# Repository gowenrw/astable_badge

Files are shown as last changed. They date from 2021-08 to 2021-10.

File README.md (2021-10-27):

# astable_badge
BSidesDFW 2021 Badge - Astable Multivibrator - Learn To Solder/Electronics/DIY

This is where all the files for the astable_badge will be stored.  
This includes code and art and cad and fab files.  All the things.

## File Structure

This is the file structure of this repository

* [/](/README.md) - YOU ARE HERE
* [/art/](./art/) - Artwork and other graphics created by this project
* [/code/](./code/) - All project related Code / Firmware
* [/docs/](./docs/) - Documentation created by this project including web pages
* [/eda/](./eda/) - Electronic Design Automation files (i.e. KiCad)
* [/reference_parts/](./reference_parts/) - Documentation pulled from other sources related to components (this is a submodule, see below)
* [./README.md](/README.md) - This File
* [./LICENSE](/LICENSE) - Currently set to MIT

Note: the reference_parts directory a link to a submodule repository.
To add it use the following cmd after downloading this template:
```
git submodule add https://github.com/gowenrw/reference_parts reference_parts
```
This will make a link to the current commit of that repo.
To update it to a newer commit after its been added use this cmd:
```
git submodule update --recursive
```

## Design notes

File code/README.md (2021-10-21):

# Code

This is where all the all project related Code / Firmware is located

## File Structure

This is the file structure of this repository

* [/](/README.md) - Home
* [/code/](/code/) - YOU ARE HERE
  * [/code/altbier_pcb/](/code/altbier_pcb/) - Code folder for the PCB(s)
  * [/code/include/](/code/include/) - Common code includes (e.g. chipset drivers, etc.) used by the other code folders

NOTE: This project has no code since it does not use an IC.

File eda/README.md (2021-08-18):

# Electronic Design Automation

This is where all the Electronic Design Automation files for the PCB(s) will be stored.
The EDA used is KiCad 5.x unless otherwise specified.

The KiCad projects have been configured to use local libraries for long term sustainability per the best practices listed [HERE](https://hackaday.com/2017/05/18/kicad-best-practises-library-management/) and elsewhere.

## File Structure

This is the file structure of this repository

* [/](/README.md) - Home
* [/eda](/eda/) - YOU ARE HERE
  * /eda/astable_badge/ - KiCad project folder for the badge PCB
    * ./3d_models/ - This directory contains footprint 3d model files
    * ./gerber/ - This directory contains gerber formatted files for manufacturing
    * ./lib_fp/ - This directory contains footprint module directories
    * ./lib_sh/ - This directory contains schematic library files
    * ./snapshots/ - This directory contains prints of schematic / cad files and images of preview / final product
  * /eda/astable_dev/ - KiCad project folder for the development PCB
    * ./3d_models/ - This directory contains footprint 3d model files
    * ./gerber/ - This directory contains gerber formatted files for manufacturing
    * ./lib_fp/ - This directory contains footprint module directories
    * ./lib_sh/ - This directory contains schematic library files
    * ./snapshots/ - This directory contains prints of schematic / cad files and images of preview / final product

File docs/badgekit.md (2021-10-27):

---
layout: default
---

# BSidesDFW 2021 Astable Badge Kit

The Astable Badge Kit contains the following items:

*  1 - PCB
*  1 - Lanyard
*  1 - Sticker
*  1 - CR2032 Battery
*  1 - Small Static Bag with the following components:
    *  5 - 3mm LEDs (1 each of Red, Green, Blue, Yellow, and White)
    *  2 - 10 ohm Resistors
    *  2 - 510 ohm Resistors
    *  2 - 1K ohm Resistors
    *  2 - 0-30K ohm Variable Resistors (a.k.a. Rheostats)
    *  2 - 100uF Polarized Capacitors
    *  2 - NPN BJT 2222A Transistors
    *  1 - CR2032 Battery Holder
    *  1 - 5x1 header pin segment

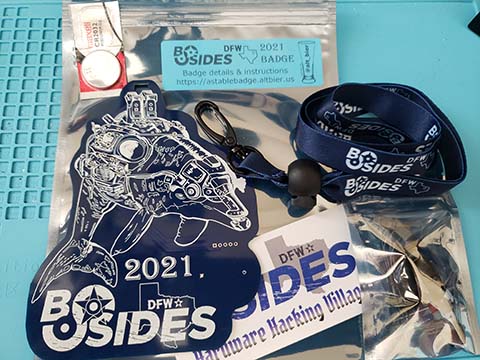
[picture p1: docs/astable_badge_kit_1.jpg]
Kit1

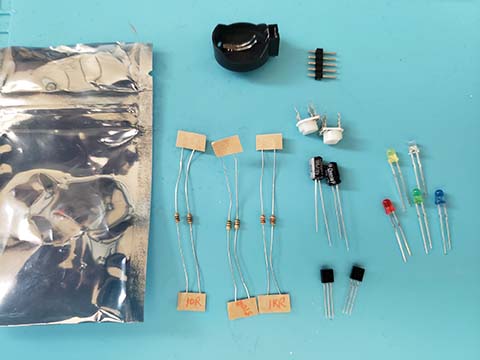
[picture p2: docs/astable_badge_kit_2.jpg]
Kit2


# Tools

In addition to the badge PCB and the small component bag that is provided, you will need the following tools:

* Soldering Iron and Solder

Any electronics soldering iron in the 40 Watt to 70 Watt range should work.  
Note that not all soldering irons are for electronics, those used for plumbing and other applications use much higher temperatures that could damage electronics.

There are different types of solder used for electronics and most of them will work fine.
The type I recommend for beginner's is 63-37 (or 60-40) Rosin Core 0.8mm solder.  
The 63-37 refers to the element percentages: 63 percent Tin and 37 percent Lead.
The Rosin Core indicates that the center of the solder wire is hollowed out and filled with Rosin which is a Flux material (so you do not need to apply Flux separately).
The diameter of 0.8mm seems to work best for most applications IMHO.

You can find kits on [Amazon](https://www.amazon.com/s?k=soldering+iron+kit) and elsewhere for less than $20 that include a Soldering Iron, Solder, a Stand, and other useful items.

* Diagonal Cutter

A good diagonal cutting tool is needed to trim the component leads once soldered.
Sometimes this is provided in a soldering iron kit.
But, usually those inexpensive kits do not provide a good cutter.

You can find a good Diagonal Cutter at [Amazon](https://www.amazon.com/s?k=diagonal+cutter) and elsewhere for less than $10.

* Small Screwdriver

A small Phillips head Screwdriver is needed for adjusting the Rheostats to change the speed at which the LEDs blink.

* Multimeter and Logic Analyzer (Optional)

Testing tools such as a multimeter and logic analyzer can be useful in troubleshooting issues with your build as well as learning the electronics that make up the badge.

You can find an inexpensive Multimeter on [Amazon](https://www.amazon.com/s?k=multimeter) and elsewhere for less than $10.

You can find an inexpensive USB Logic Analyzer on [Amazon](https://www.amazon.com/s?k=usb+logic+analyzer+-+24mhz+8-channel) and elsewhere for less than $15.

# Instructions

This is a learn to solder / electronics badge.
The schematic of the circuit you will be building is printed on the back of the badge.
In addition, the back of the badge details out the placement of the components to be soldered.

All of the components that you will be soldering have through hole or THT packaging.  This means that they have metal leads that will be placed into the appropriate holes in the PCB and soldered in place.

These components can be added and soldered to the PCB in any order you wish.  These instructions will outline how I build the badge, but feel free to build as you like.

## Resistors

There are a total of six resistors, two each of the values 10 Ohm, 510 Ohm, and 1K Ohm.

The resistors come attached to paper which has the value labeled on it.  If you need to determine the value of a resistor once removed from that paper you can view the colored stripes on the body of the resistor and look it up on a resistor value chart such as this one from [wikipedia](https://en.wikipedia.org/wiki/Electronic_color_code#Resistors).

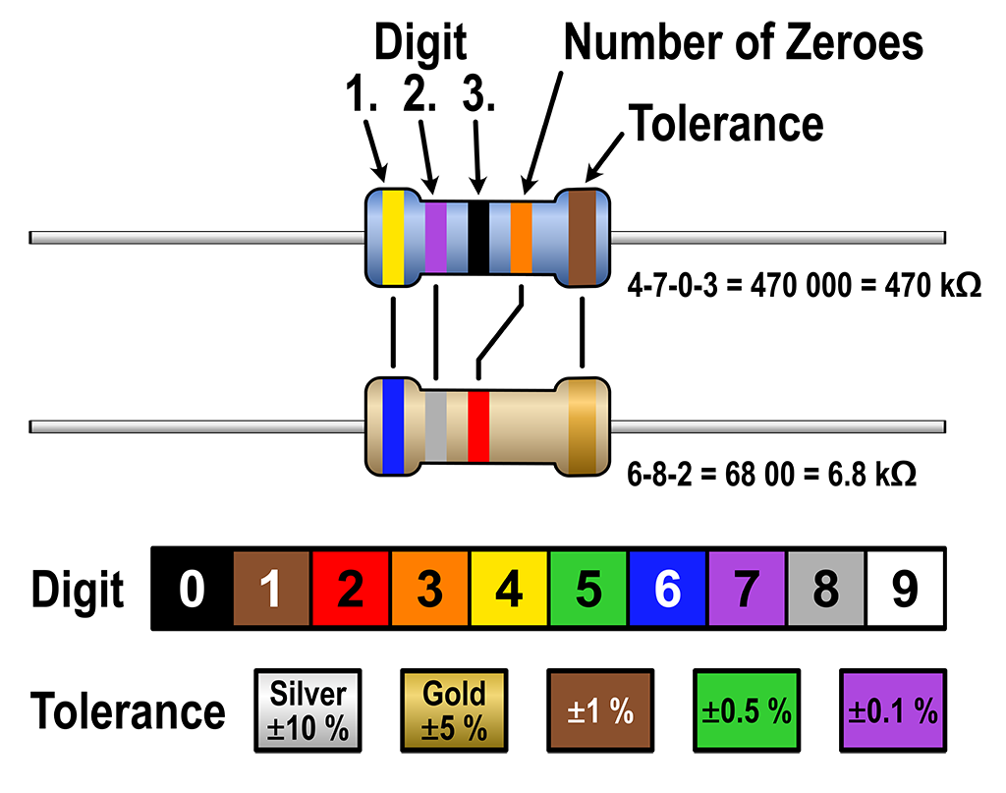
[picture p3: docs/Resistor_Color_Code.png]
Resistor_Color_Codes


Identify the area on the badge where the components will need to be installed by looking at the component labels on the back of the PCB.

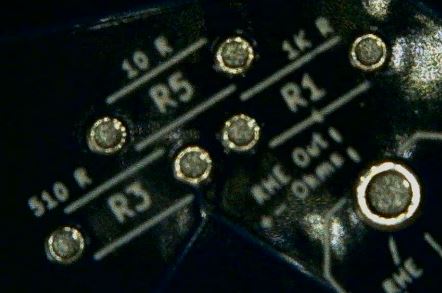
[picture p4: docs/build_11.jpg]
Build_11


Remove the resistors from the paper and bend their leads 90 degrees.

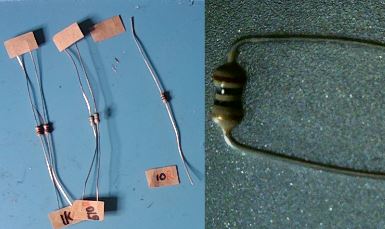
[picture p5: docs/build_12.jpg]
Build_12


Insert the resistors into the proper holes as labeled on the back of the PCB.

The resistor body should be on the front of the PCB with the leads coming through the holes to the back of the PCB.

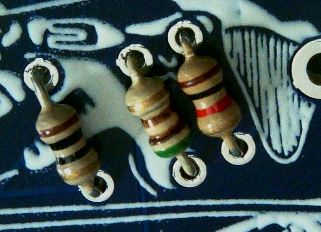
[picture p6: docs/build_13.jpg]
Build_13

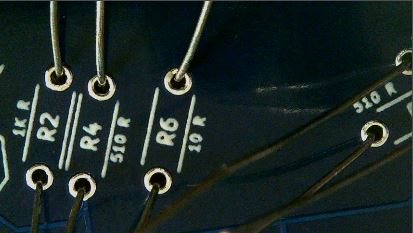
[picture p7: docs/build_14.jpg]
Build_14


Solder those leads in place.

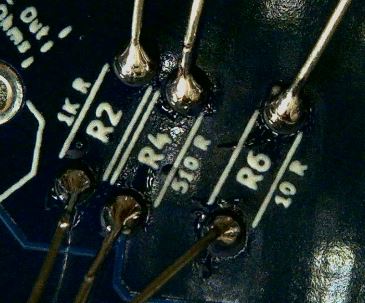
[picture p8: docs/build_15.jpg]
Build_15


Trim the leads with a diagonal cutter taking care not to trim too close to the solder joint.

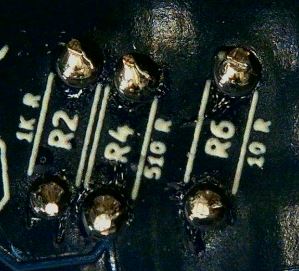
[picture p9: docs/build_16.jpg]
Build_16


## Transistors

There are two NPN BJT Transistors of the model 2222A.  

Identify the area on the badge where the components will need to be installed by looking at the component labels on the back of the PCB.

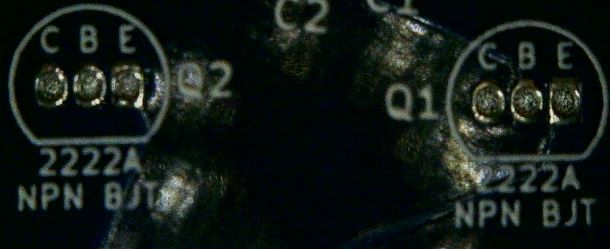
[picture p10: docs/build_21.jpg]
Build_21


These Transistors have a flat side and a rounded side to allow for proper alignment when placing on the PCB.

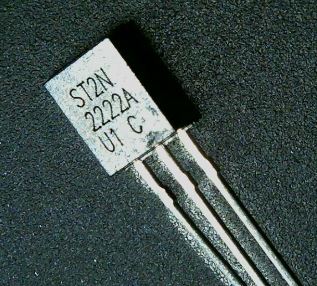
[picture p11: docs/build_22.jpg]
Build_22


Insert the Transistors into the proper holes as labeled on the back of the PCB.

The Transistor body should be on the front of the PCB with the leads coming through the holes to the back of the PCB.

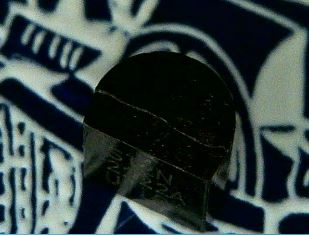
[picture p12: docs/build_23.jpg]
Build_23

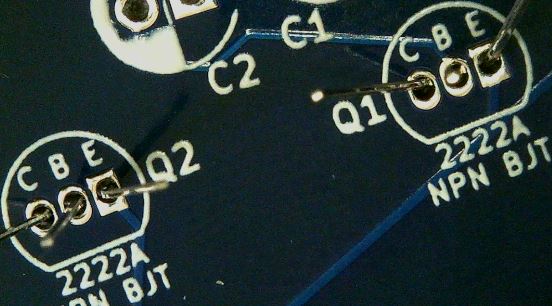
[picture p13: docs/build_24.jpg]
Build_24


Solder those leads in place.
The holes for these components are close together.
Be careful not to bridge (solder together) any of the Transistor connections.

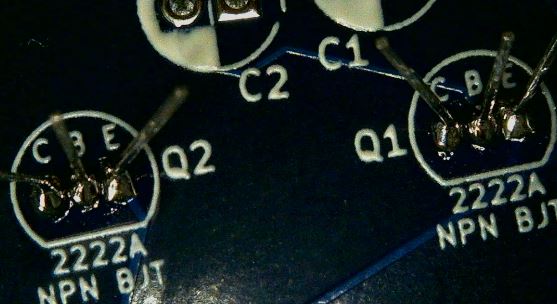
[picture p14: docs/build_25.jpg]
Build_25


Trim the leads with a diagonal cutter taking care not to trim too close to the solder joint.

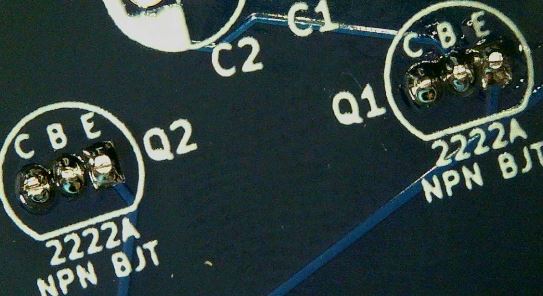
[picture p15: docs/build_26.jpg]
Build_26


## Rheostats (Variable Resistors)

There are two Variable Resistors also known as Rheostats which each have 3 pins and a resistance range of 0 to 30K Ohms.

Identify the area on the badge where the components will need to be installed by looking at the component labels on the back of the PCB.

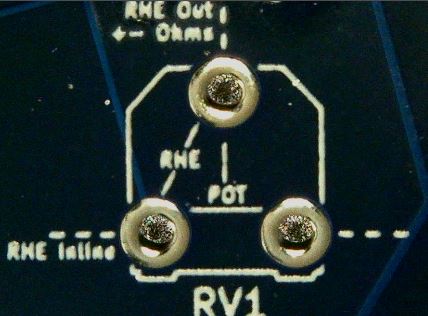
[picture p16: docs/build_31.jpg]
Build_31


These Rheostats have a unique shape with cutouts on one side to allow for proper alignment when placing on the PCB.

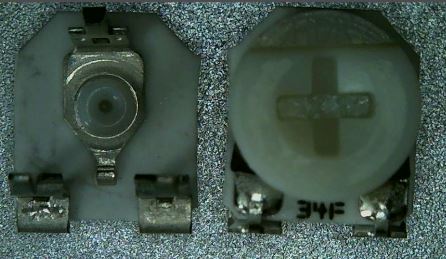
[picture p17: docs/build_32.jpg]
Build_32


Insert the Rheostats into the proper holes as labeled on the back of the PCB.

The Rheostats body should be on the front of the PCB with the leads coming through the holes to the back of the PCB.
Note that the leads are made in such a way as to act as standoffs keeping the body of the Rheostat raised above the PCB.

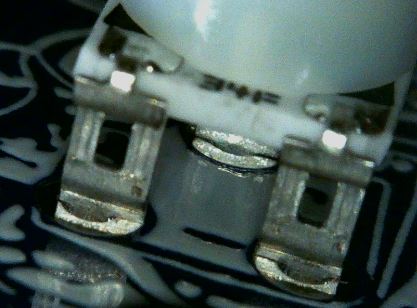
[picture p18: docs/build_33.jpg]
Build_33

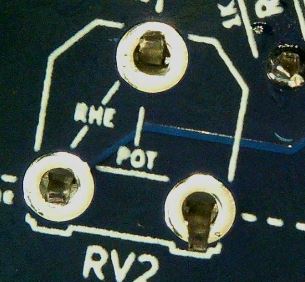
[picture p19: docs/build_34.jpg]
Build_34


Solder those leads in place.

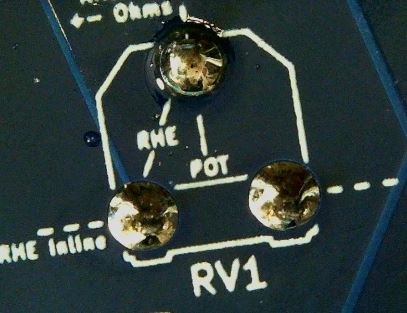
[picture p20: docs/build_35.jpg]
Build_35


These leads should be close enough to the PCB that they do not need to be trimmed with the cutter.

## Capacitors

There are two Polarized Capacitors with the value of 100uF 10V.  Polarized Capacitors are directional components that must be placed with positive and negative terminals in the proper direction.

Identify the area on the badge where the components will need to be installed by looking at the component labels on the back of the PCB.

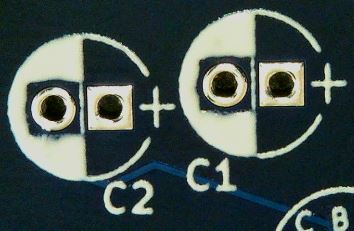
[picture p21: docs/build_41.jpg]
Build_41


These Capacitors have a white stripe indicating the negative terminal which also has a shorter lead wire.  This should allow for proper alignment when placing on the PCB.

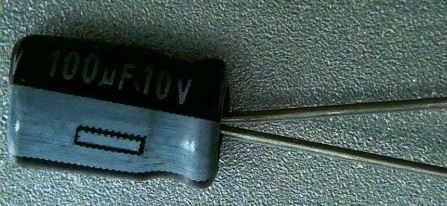
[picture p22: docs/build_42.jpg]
Build_42


Insert the Capacitors into the proper holes as labeled on the back of the PCB.

The Capacitor body should be on the front of the PCB with the leads coming through the holes to the back of the PCB.

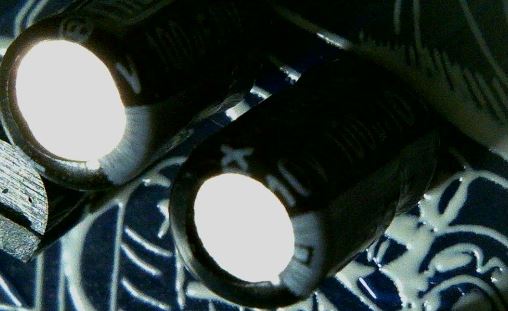
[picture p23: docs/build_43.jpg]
Build_43

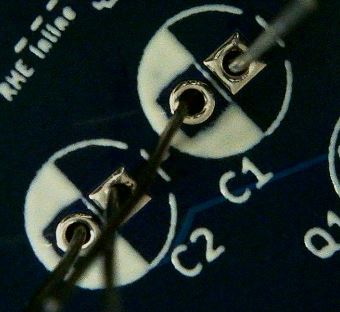
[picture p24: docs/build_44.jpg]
Build_44


Solder those leads in place.

Build_45

Trim the leads with a diagonal cutter taking care not to trim too close to the solder joint.

Build_46

## LEDs

There are two LEDs of the 3mm size that you will use on the badge.  These LEDs are directional components that must be placed with positive and negative terminals in the proper direction.

You were provided five LEDs in different colors to allow you to choose the two colors you would like to use.

Identify the area on the badge where the components will need to be installed by looking at the component labels on the back of the PCB.

Build_51

These LEDs have a small flat notch on the otherwise round base indicating the negative terminal which also has a shorter lead wire.  The PCB component label has a small triangle that points to the where the negative terminal should be placed. This should allow for proper alignment when placing on the PCB.

Build_52

Insert the LEDs into the proper holes as labeled on the back of the PCB.

The LED body should be on the front of the PCB with the leads coming through the holes to the back of the PCB.

Build_53
Build_54

Solder those leads in place.

Build_55

Trim the leads with a diagonal cutter taking care not to trim too close to the solder joint.

Build_56

## Battery Holder

There is one battery holder for a CR2032 sized battery.  It is directional in that it must be placed with positive and negative terminals in the proper direction.

Identify the area on the badge where the components will need to be installed by looking at the component labels on the back of the PCB.

Build_61

This battery holder has a distinctive shape that should allow for proper alignment when placing on the PCB.

Build_62

Insert the battery holder into the proper holes as labeled on the back of the PCB.

The battery holder body should be on the front of the PCB with the leads coming through the holes to the back of the PCB.

Build_63
Build_64

Solder those leads in place.

Build_65

These leads should be close enough to the PCB that they do not need to be trimmed with the cutter.

## Test Header Pins

The test header pins are an optional component you can add to aid with testing later.  These are standard 1.25mm pitch header pins in a single row of five pins.

Place these header pins into the proper holes as labeled on the back of the PCB.

Build_72

Solder those leads in place.

Build_75

These leads should be close enough to the PCB that they do not need to be trimmed with the cutter.

## Operational Test

To test the badge once you are finished building it simply insert a battery.

The CR2032 battery should be inserted into the battery holder with the Plus (+) sign showing up.

If all worked well you should see the two LEDs start to blink on and off.

You can adjust the speed that the LEDs blink by adjusting the Rheostats with a Screwdriver.

Build_80

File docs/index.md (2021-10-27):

---
layout: default
---

Hero Image

# Astable Badge

Welcome to the Astable Badge website.

This is where you will find information about the BSidesDFW 2021 Badge and its repository.

-- [@alt_bier](https://twitter.com/alt_bier)  - [My Contact Info](https://gowen.net/about)

Animated

---

# Badge Kit Instructions

If you are looking for what comes in the badge kit or instructions on how to build the badge, those details are here: [Badge Kit](badgekit.md)

# Concept

The concept for this badge started [@CyberLowdown](https://twitter.com/CyberLowdown) asking me if I would be willing to do the badge for the BSidesDFW 2021 conference and with [@0isac0](https://twitter.com/0isac0) asking me if we can do a [Johnny Mnemonic](https://www.imdb.com/title/tt0113481/) theme since that movie takes place in 2021.
After much research I settled on a Cyber-Dolphin for the principal focus of the badge.

Given how the global chip shortages affected my recent Defcon badge I needed a circuit design that would flash some LEDs without the use of an IC chip.  This is what drove the circuit design.

Another design factor was that I wanted to make it a learning badge (learn soldering and electronics).  I've had great feedback on my other learning badges and I thought this would be a great draw to the BSidesDFW Hardware Hacking Village (which I would be running) to help people build their badges.

## Art

The badge art using a Johnny Mnemonic theme had me stumped on what to do since I did not just want to put Keanu Reeves face on a PCB (plus that's been done before).

So I did some research online and still had nothing.  I then reached out to some other badge makers and the idea of the Cyborg or Cyber Dolphin was mentioned.  It had been a long time since I watched that movie and didn't remember a Dolphin so I re-watched it and sure enough it was there.  

I loved the aesthetic and the Cyber-Dolphin badge art was born.

Badge_Front_sm
CyberDolphin_sm

All of the Art files including the Adobe Illustrator files and various exported formats are available in the [art directory](https://github.com/gowenrw/astable_badge/tree/main/art) of this repository.

# Details

I wanted to make this a learn to solder and learn electronics badge.
All of the components are Through Hole type to meet the learn to solder goal.
The circuit needed to be complex enough to blink some LEDs without using an IC chip but simple enough for people to easily see what it is doing to learn from it.
The Astable Multivibrator circuit was perfect to meet the learn electronics goal.

Badge_Assembled

## Astable Multivibrator

The Astable Multivibrator is a type of transistor switching circuit that has NO stable output states as it changes from one state to the other all the time.

The astable circuit consists of two switching transistors getting feedback from two time delay capacitor-resistor couplings.
This allows oscillation between the two states with no external triggering to produce the change in state.

On this badge I opted to introduce variable resistors (Rheostats) into the time delay capacitor-resistor couplings to allow for the speed of the state changes to be adjusted.
I added LEDs to the outputs of this circuit providing visual representation of the circuit state changes (and blinky lights).
I also added test points to the PCB so that the alternating square waves produced by this circuit could be observed with a cheap logic analyzer.

Astable Multivibrator Circuit Schematic
Astable_Multivibrator

## EDA

The electronic design automation program used for this badge is KiCad.

I took great care to include and use local library files for all the schematic objects, footprints, and 3d models used in this badge.  
This way you don't have to worry about not having a file that KiCad depreciates at some point in the future.

All of the EDA files including the Gerber output files I used to have the badge manufactured are available in the [badge eda directory](https://github.com/gowenrw/astable_badge/tree/main/eda/astable_badge) of this repository.

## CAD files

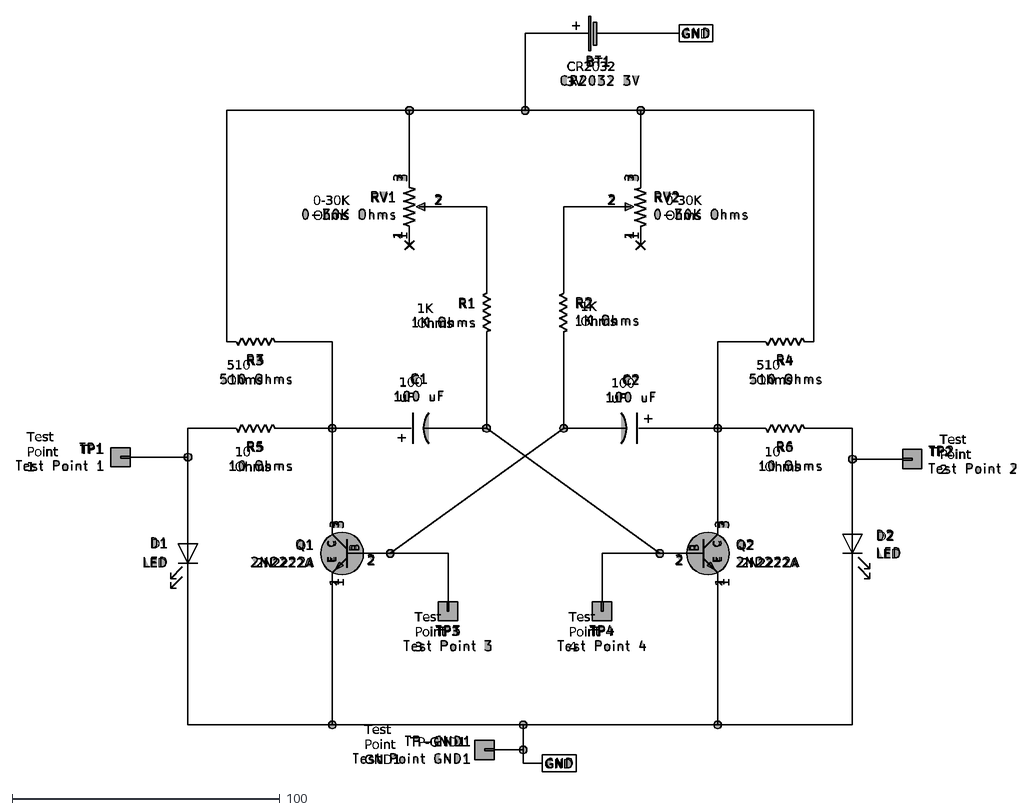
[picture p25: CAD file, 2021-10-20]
art/astable_badge_schem-back_silk.dxf
C1
100 uF
D2
LED
R4
510 Ohms
D1
TP1
Test Point 1
R3
TP-GND1
Test Point GND1
1
2
3
RV2
0-30K Ohms
RV1
TP2
Test Point 2
TP3
Test Point 3
TP4
Test Point 4
R6
10 Ohms
R5
C2
B
C
E
Q1
2N2222A
Q2
R2
1K Ohms
R1
BT1
CR2032 3V
GND

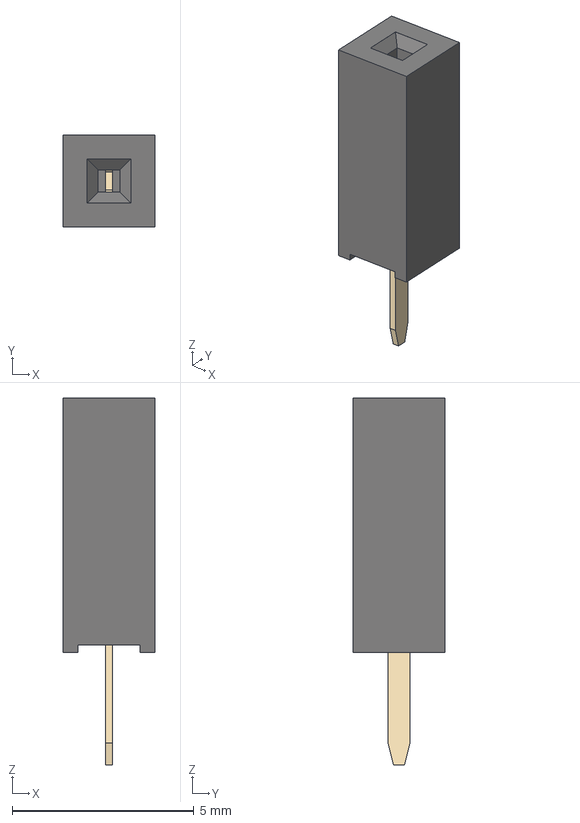
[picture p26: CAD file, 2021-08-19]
eda/astable_badge/3d_models/PinSocket_1x01_P2.54mm_Vertical.step
2.54 x 2.54 x 10.1 mm

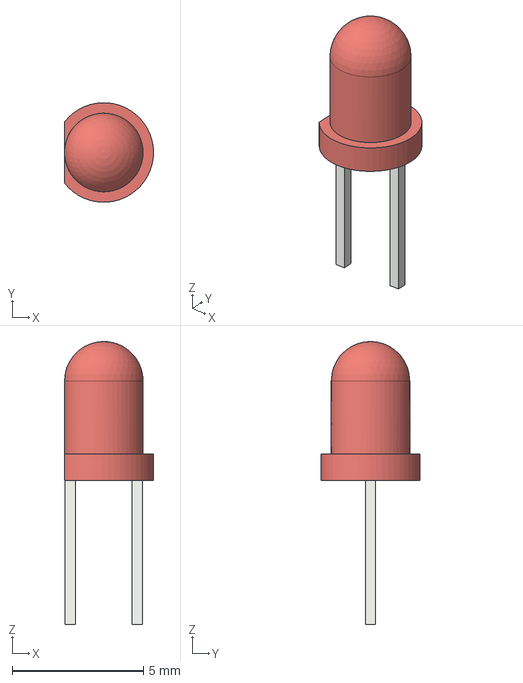
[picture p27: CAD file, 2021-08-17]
eda/astable_dev/3d_models/LED_D3.0mm.step
3.40 x 3.80 x 10.8 mm

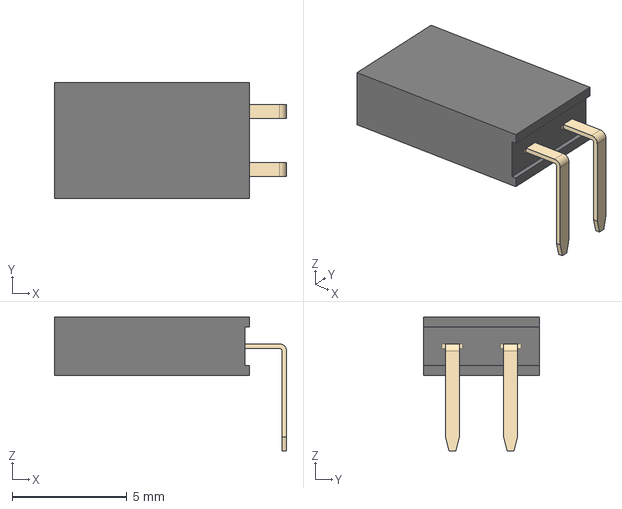
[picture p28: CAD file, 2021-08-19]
eda/astable_badge/3d_models/PinSocket_1x02_P2.54mm_Horizontal.step
10.1 x 5.08 x 5.84 mm

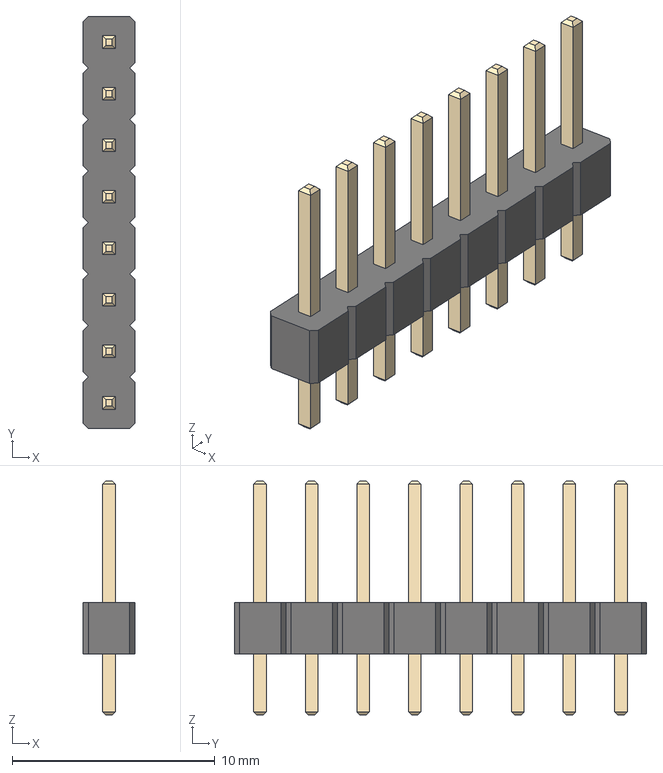
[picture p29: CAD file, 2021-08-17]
eda/astable_dev/3d_models/PinHeader_1x08_P2.54mm_Vertical.step
2.54 x 20.3 x 11.5 mm

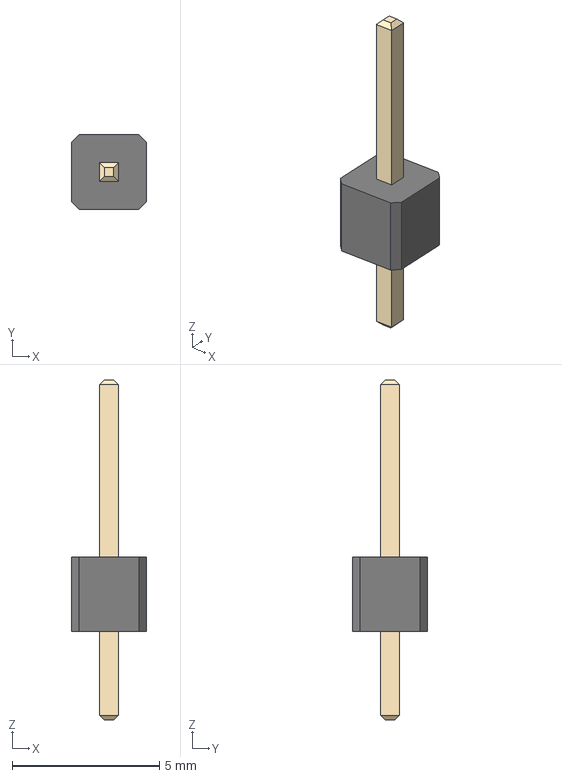
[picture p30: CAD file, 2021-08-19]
eda/astable_badge/3d_models/PinHeader_1x01_P2.54mm_Vertical.step
2.54 x 2.54 x 11.5 mm

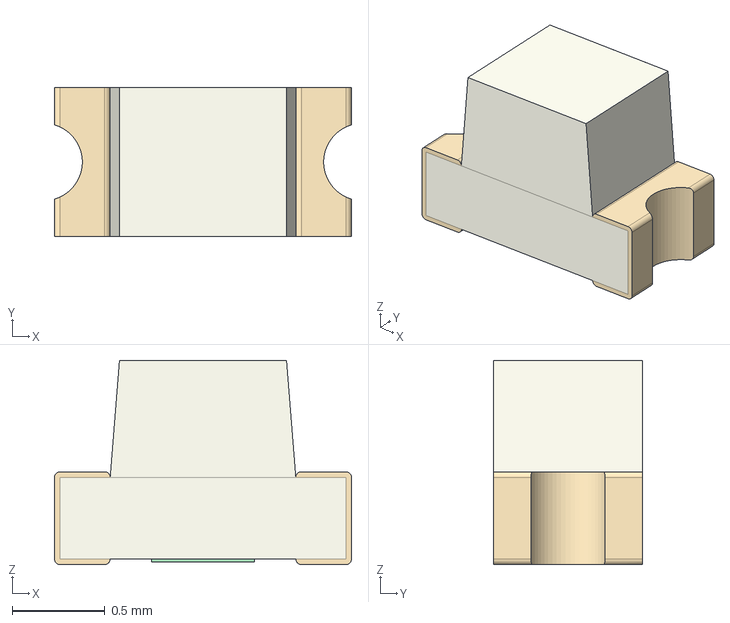
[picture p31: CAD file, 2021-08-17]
eda/astable_dev/3d_models/LED_0603_1608Metric_Castellated.step
1.60 x 0.8 x 1.10 mm

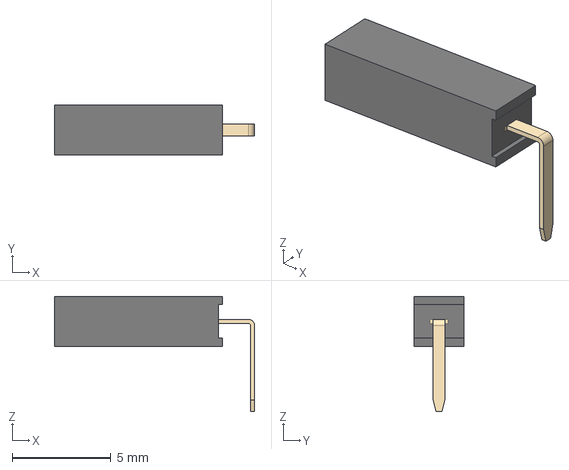
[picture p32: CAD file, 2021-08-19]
eda/astable_badge/3d_models/PinSocket_1x01_P2.54mm_Horizontal.step
10.1 x 2.54 x 5.84 mm

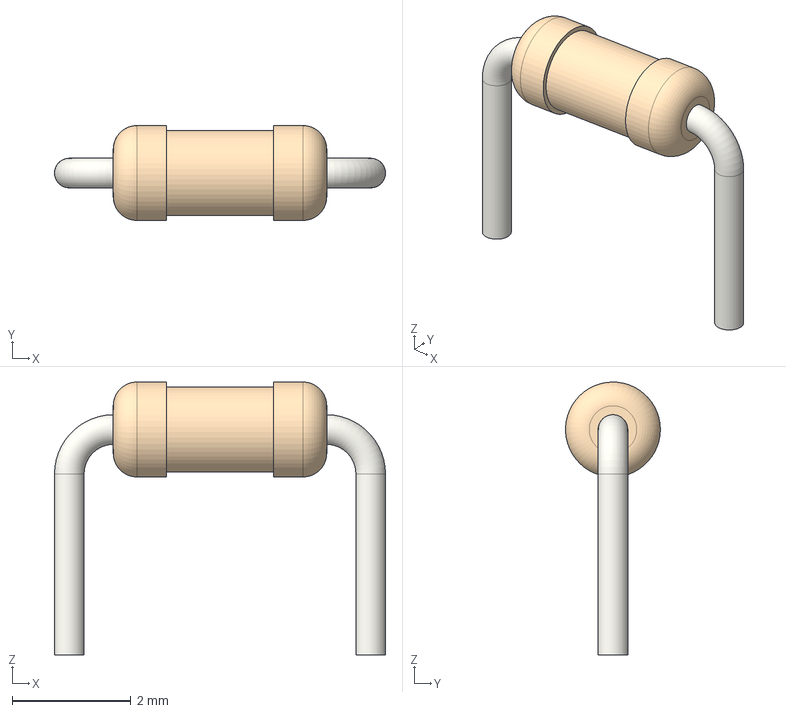
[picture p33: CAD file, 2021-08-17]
eda/astable_dev/3d_models/R_Axial_DIN0204_L3.6mm_D1.6mm_P5.08mm_Horizontal.step
5.58 x 1.60 x 4.60 mm

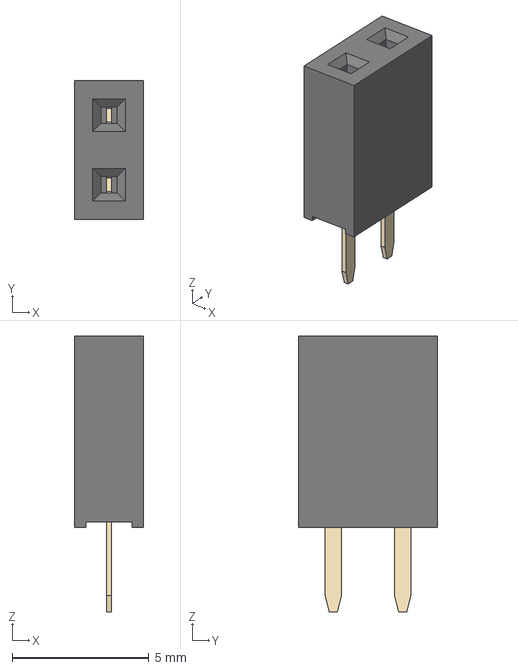
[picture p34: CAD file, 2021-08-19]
eda/astable_badge/3d_models/PinSocket_1x02_P2.54mm_Vertical.step
2.54 x 5.08 x 10.1 mm

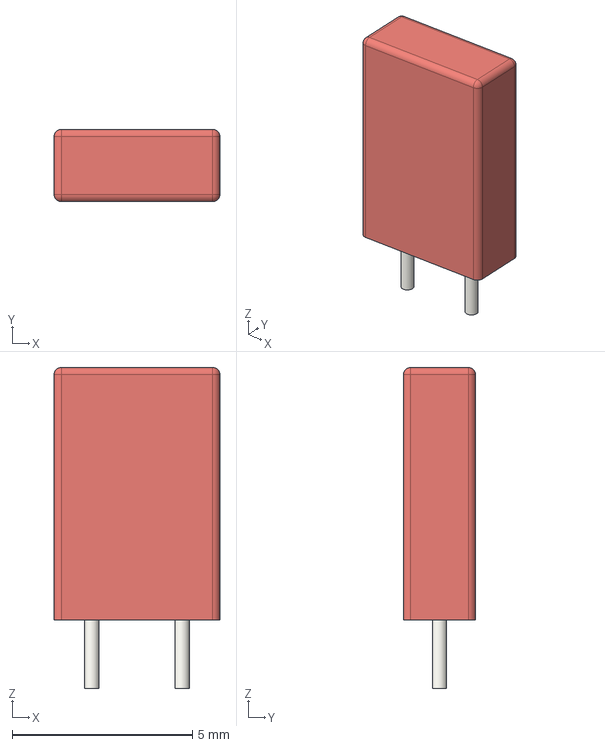
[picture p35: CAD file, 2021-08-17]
eda/astable_dev/3d_models/C_Rect_L4.6mm_W2.0mm_P2.50mm_MKS02_FKP02.step
4.60 x 2.00 x 8.90 mm

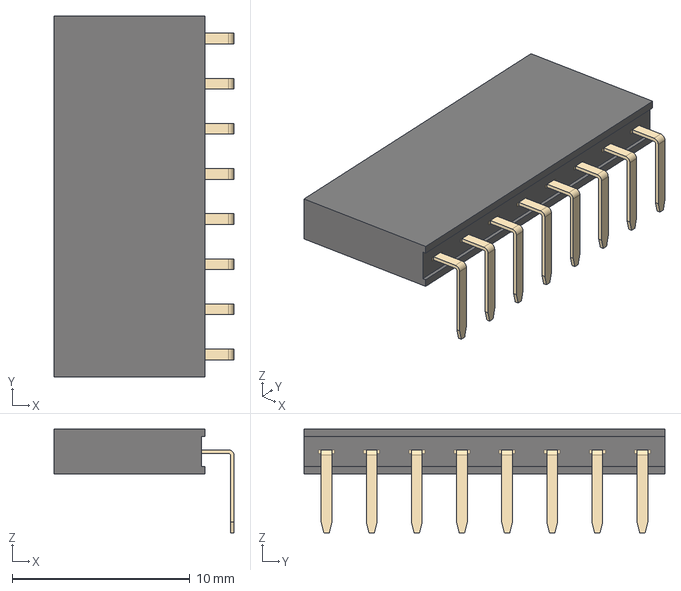
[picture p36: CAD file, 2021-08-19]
eda/astable_badge/3d_models/PinSocket_1x08_P2.54mm_Horizontal.step
10.1 x 20.3 x 5.84 mm

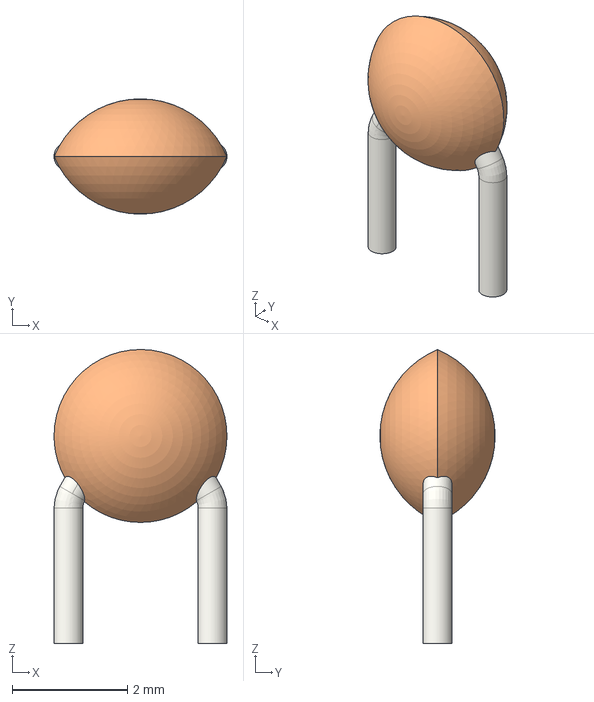
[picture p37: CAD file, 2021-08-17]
eda/astable_dev/3d_models/C_Disc_D3.0mm_W2.0mm_P2.50mm.step
3.00 x 2.00 x 5.10 mm

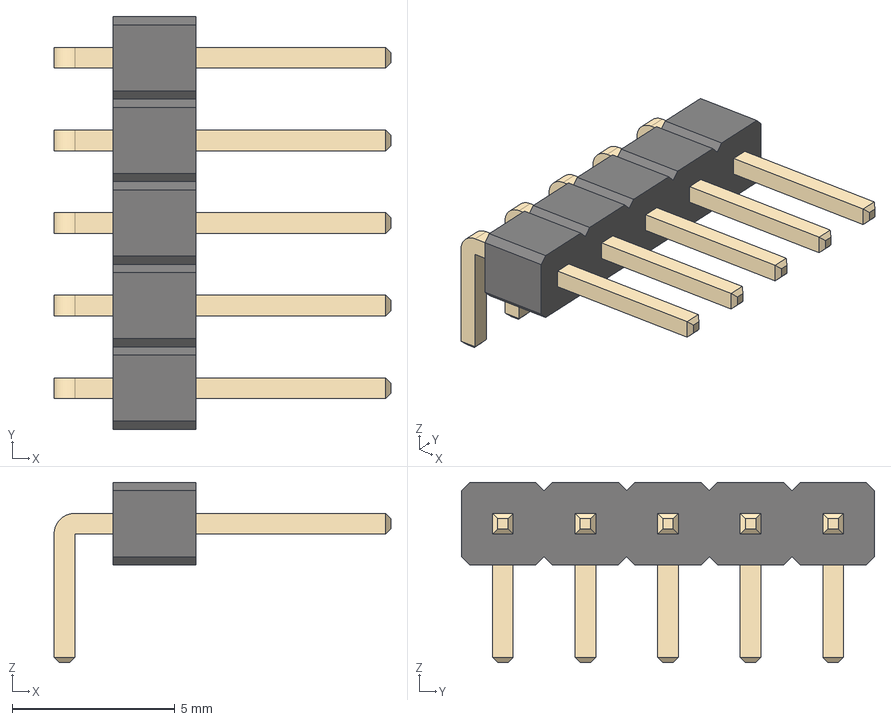
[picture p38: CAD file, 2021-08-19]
eda/astable_badge/3d_models/PinHeader_1x05_P2.54mm_Horizontal.step
10.4 x 12.7 x 5.54 mm

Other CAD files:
eda/astable_dev/3d_models/LED_1206_3216Metric.step
eda/astable_badge/3d_models/PinSocket_1x08_P2.54mm_Vertical.step
eda/astable_dev/3d_models/CP_Radial_D6.3mm_P2.50mm.step
eda/astable_badge/3d_models/PinHeader_1x05_P2.54mm_Vertical.step
eda/astable_badge/3d_models/Battery_Holder_3xAAA_Simple.step
eda/astable_badge/3d_models/Battery_Holder_CR2032_BS-2-1.stp
eda/astable_badge/3d_models/CP_Radial_D5.0mm_P2.00mm.step
eda/astable_badge/3d_models/CP_Radial_D6.3mm_P2.50mm.step
eda/astable_badge/3d_models/C_0603_1608Metric.step
eda/astable_badge/3d_models/C_0805_2012Metric.step
eda/astable_badge/3d_models/C_1206_3216Metric.step
eda/astable_badge/3d_models/LED_0603_1608Metric.step
eda/astable_badge/3d_models/LED_0805_2012Metric.step
eda/astable_badge/3d_models/LED_0805_2012Metric_Castellated.step
eda/astable_badge/3d_models/LED_1206_3216Metric.step
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

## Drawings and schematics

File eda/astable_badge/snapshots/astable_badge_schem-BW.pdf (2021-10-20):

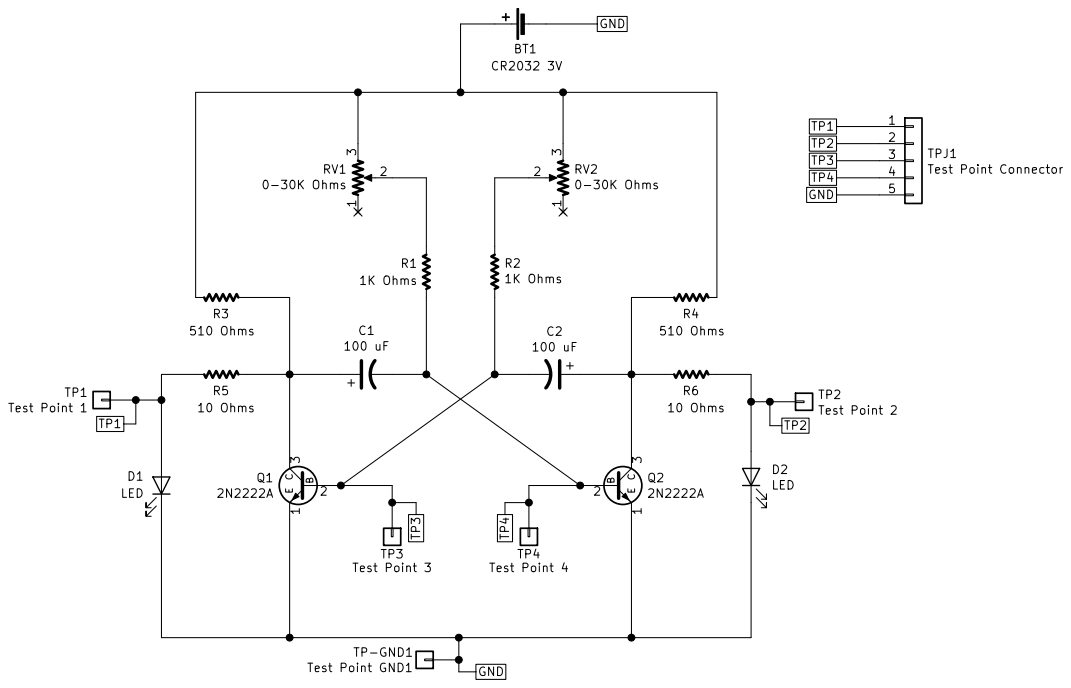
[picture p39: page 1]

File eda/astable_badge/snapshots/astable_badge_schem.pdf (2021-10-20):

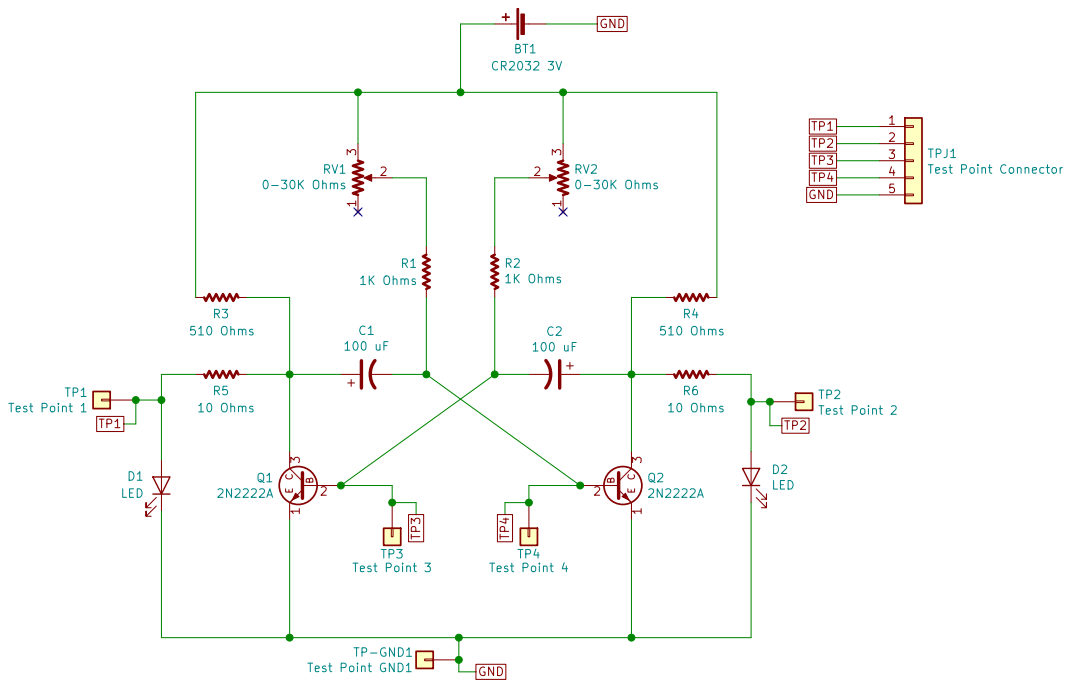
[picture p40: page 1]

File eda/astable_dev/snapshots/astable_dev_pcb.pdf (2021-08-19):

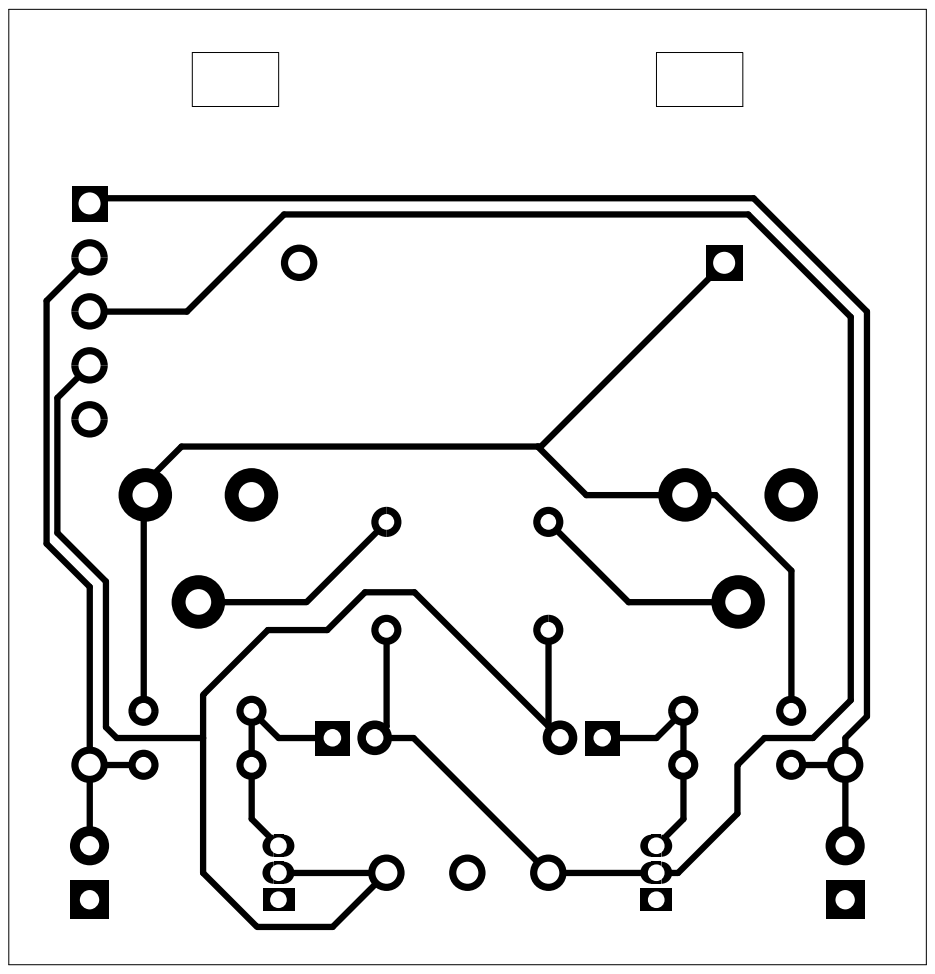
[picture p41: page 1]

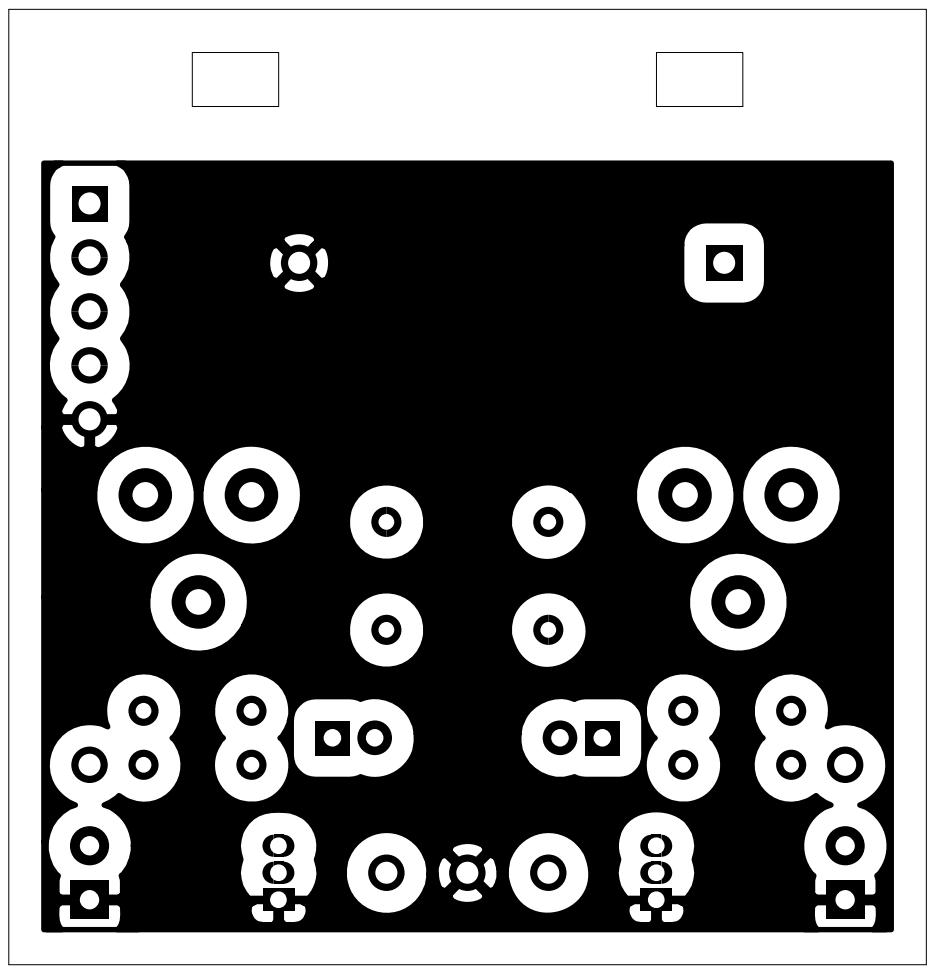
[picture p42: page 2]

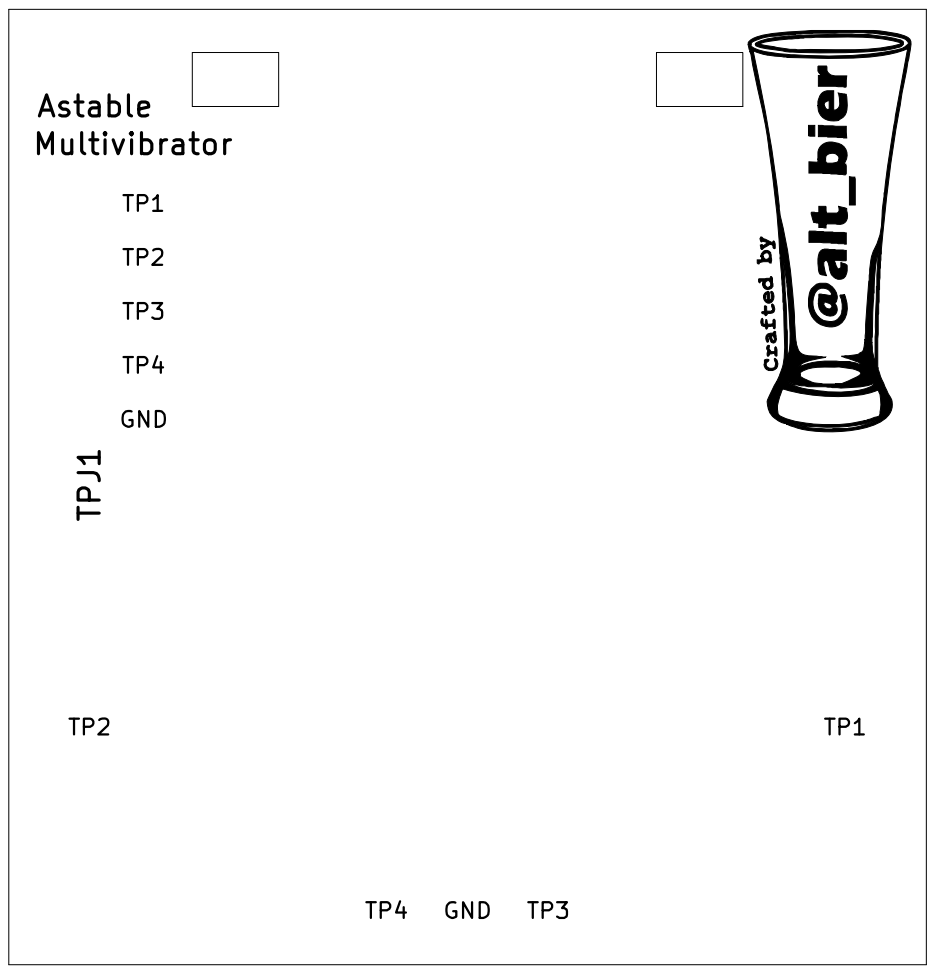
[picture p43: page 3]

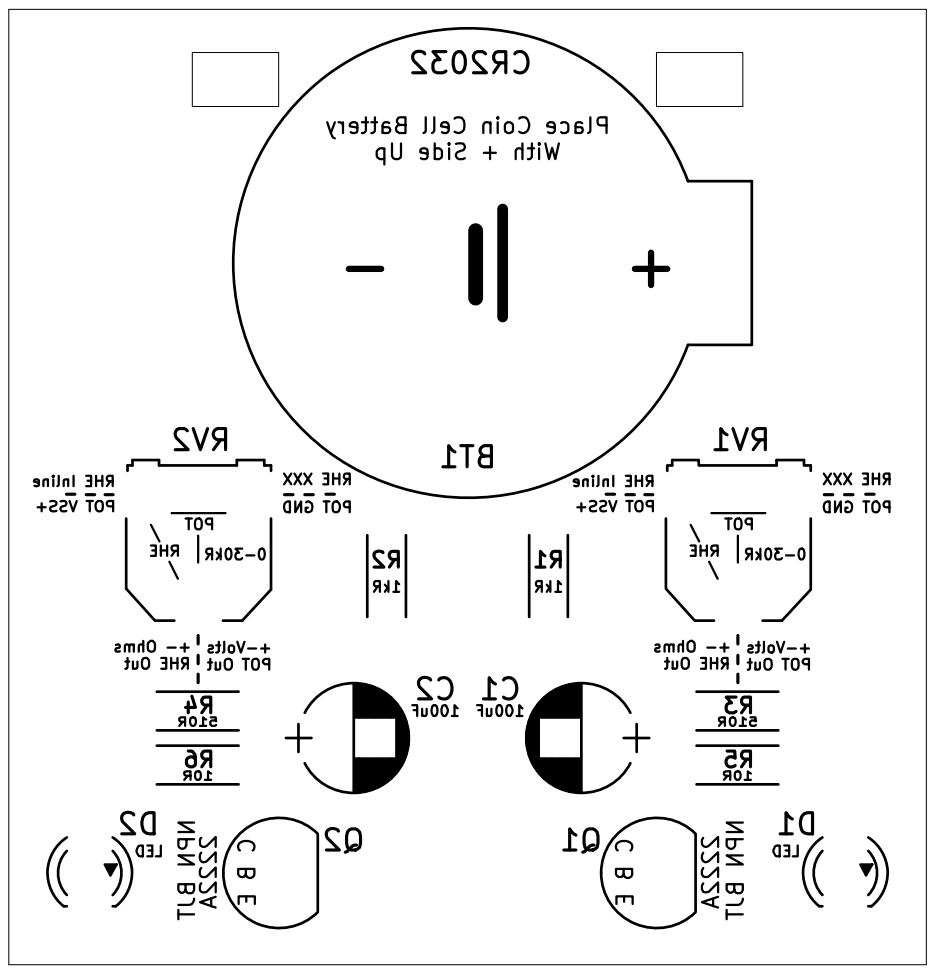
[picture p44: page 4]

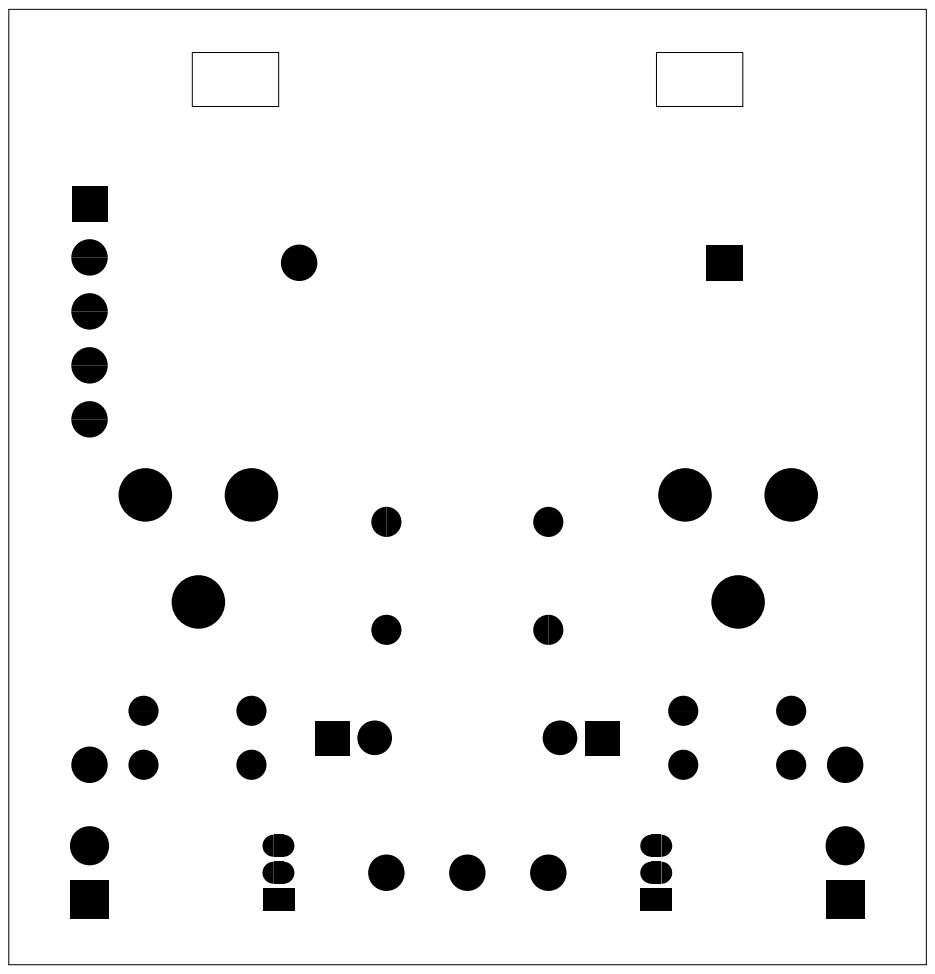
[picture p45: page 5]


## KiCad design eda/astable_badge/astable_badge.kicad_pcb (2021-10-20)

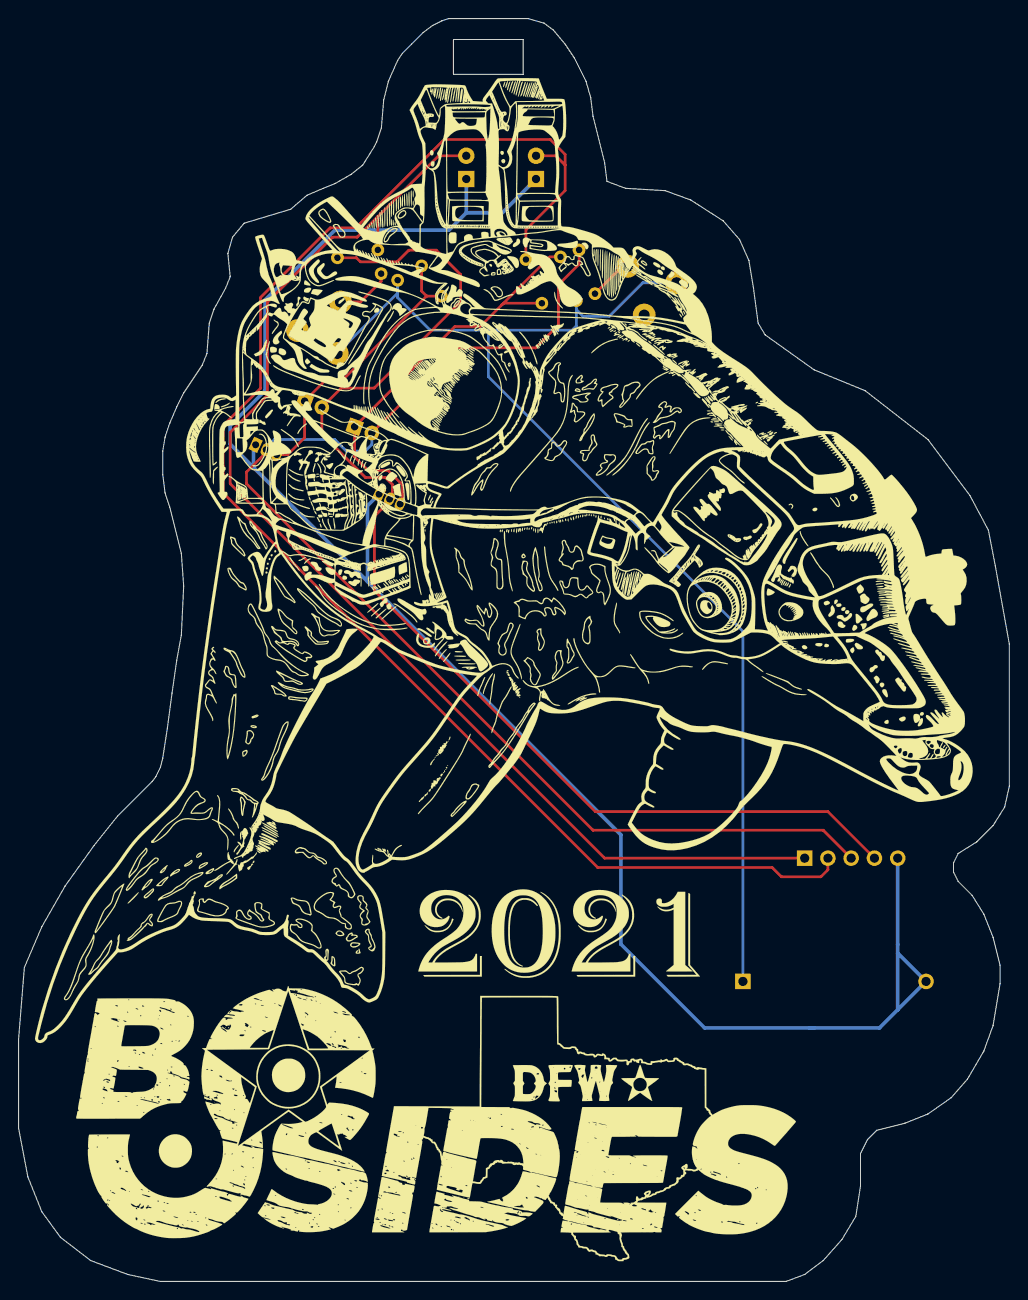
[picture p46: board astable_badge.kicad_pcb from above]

Board: 2 copper layers, 108.2 x 137.9 mm, 16 parts (0 on the bottom side), 10 nets.

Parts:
BT1: CR2032 3V; BatteryHolder_CR2032-BS-2-1_Front_backsilk
C1, C2: 100 uF; CP_Radial_D5.0mm_P2.00mm_backsilk
D1, D2: LED; LED_D3.0mm-2_backsilk
Q1, Q2: 2N2222A; Q_2222A_TO-92_Inline_back-silk
R1, R2: 1K R; R_Axial_DIN0204_L3.6mm_D1.6mm_P5.08mm_Horizontal_backsilk
R3, R4: 510 R; R_Axial_DIN0204_L3.6mm_D1.6mm_P5.08mm_Horizontal_backsilk
R5, R6: 10 R; R_Axial_DIN0204_L3.6mm_D1.6mm_P5.08mm_Horizontal_backsilk
RV1, RV2: 0-30K Ohms; R_Potentiometer_3pin_THT_5mm_backsilk_anno
TPJ1: Test Point Connector; Conn_Pin_Header_Hole_1x05_Pitch2.54mm

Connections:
GND: BT1.2, D1.1, D2.1, Q1.1, Q2.1, TPJ1.5
unnamed: BT1.1, R3.1, R4.2, RV1.3, RV2.3
unnamed: C1.1, Q1.3, R3.2, R5.2
unnamed: C2.1, Q2.3, R4.1, R6.1
unnamed: R1.1, RV1.2
unnamed: R2.2, RV2.2
TP1: D1.2, R5.1, TPJ1.1
TP2: D2.2, R6.2, TPJ1.2
TP3: C2.2, Q1.2, R2.1, TPJ1.3
TP4: C1.2, Q2.2, R1.2, TPJ1.4

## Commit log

2021-08-17 initial template push
    [Battery_Holder_3xAAA_Simple.step, CP_Radial_D6.3mm_P2.50mm.step, C_0603_1608Metric.step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]
2021-08-17 eda initial file layout
    [Battery_Holder_3xAAA_Simple.step, CP_Radial_D6.3mm_P2.50mm.step, C_0603_1608Metric.step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]
2021-08-18 Added schematic symbols and footprints
    [Battery_Holder_CR2032_BS-2-1.stp, CP_Radial_D5.0mm_P2.00mm.step, TO-92_Inline.step]
2021-08-19 dev board complete
    [PinHeader_1x01_P2.54mm_Horizontal.step, PinHeader_1x01_P2.54mm_Vertical.step, PinHeader_1x05_P2.54mm_Horizontal.step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]
2021-10-04 Preparing badge EDA
    [Battery_Holder_CR2032_BS-2-1.stp, CP_Radial_D5.0mm_P2.00mm.step, PinHeader_1x01_P2.54mm_Horizontal.step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]
2021-10-20 Final badge art and EDA updates.
    [astable_badge-B_Cu.gbl, astable_badge-B_Mask.gbs, astable_badge-B_Paste.gbp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]

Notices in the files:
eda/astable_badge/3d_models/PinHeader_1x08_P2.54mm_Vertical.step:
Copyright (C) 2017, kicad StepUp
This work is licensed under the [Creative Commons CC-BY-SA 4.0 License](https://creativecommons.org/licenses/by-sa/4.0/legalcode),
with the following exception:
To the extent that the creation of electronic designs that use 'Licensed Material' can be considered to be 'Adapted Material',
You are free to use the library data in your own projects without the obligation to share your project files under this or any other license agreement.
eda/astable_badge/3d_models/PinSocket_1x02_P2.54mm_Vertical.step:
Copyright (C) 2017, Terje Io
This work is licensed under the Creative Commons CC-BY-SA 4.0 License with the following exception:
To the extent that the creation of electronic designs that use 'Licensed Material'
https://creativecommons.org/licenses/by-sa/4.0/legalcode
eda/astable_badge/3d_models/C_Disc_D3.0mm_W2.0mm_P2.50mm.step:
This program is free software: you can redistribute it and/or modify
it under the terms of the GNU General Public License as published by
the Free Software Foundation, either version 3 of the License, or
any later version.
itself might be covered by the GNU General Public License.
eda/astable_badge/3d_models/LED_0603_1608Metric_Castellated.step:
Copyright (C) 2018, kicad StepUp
